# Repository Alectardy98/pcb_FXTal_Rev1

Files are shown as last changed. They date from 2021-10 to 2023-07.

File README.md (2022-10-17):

# FXTal Rev. 1 
    A Drop In Replacement PCB For The IBM Model F XT
                                            
capture-2022-10-17T17_19_43 746Z
capture-2022-10-17T17_19_39 296Z

All Supported Layouts can be seen [HERE](http://www.keyboard-layout-editor.com/#/gists/daab9567d1fe4691fd52719a6adab8b0)

xwhatsit/QMK atmega32u4 pcb for the IBM Model F XT and IBM Bigfoot

This version has been tested and has shown to function properly in both supported layouts.
- The firmware can be found in the firmware folder
- All files for production though JLCPCB can be found in the JLCPCB folder
- This pcb requires an xwhatsit to function, see [purdeaandrei's open source files](https://github.com/purdeaandrei/SMDModelFController)
- Test Points are currently on the pcb, when building make sure to cover the bottom test points with eletrical tape to prevent a short
- The origonal backplate will need to be modified to remove the right PCB mounting peg, to prevent interfearance
- The barrel Plate will need to be modified, a scan of the required holes are provided in folder meta, to help with the task

The PCB thickness should be 0.6mm or 0.08mm. This is thin enough to allow the board to flex into shape.
- 0.8mm tested and working

Standard glossy soldermask is probably the best choice. JLCPCB has had issues with wear on their black soldermask before. They have changed the formula, but a standard green/red/blue/yellow/purple/white/etc. glossy solder mask is probaby the safest bet for keyswitch wear resistance. Higher wear resistance might also be achieved by coating the front of the capacitive pads in silkscreen, as silkscreen is an extra layer of epoxy. I am unsure how this will affect keyfeel or actuation, however.

For connecting the board to an xwhatsit or other controller, I would recommend [3M 8132/06 100](https://www.digikey.com/en/products/detail/3m/8132-06-100/7809902), which has the correct pitch to connect this pcb to an xwhatsit

Capacitive pad footprints have been taken dvjs project the mtf-capacitive Other mesurements have been taken by NeonKight and myself from an origonal IBM F XT. The key matrix of the PCB is custom, made by myself guided by dvjs and purdeaandrei.

Released without warranty, use at your own risk.  
PRs & feedback welcome!

| Authors | 

Alectardy98

| Special Thanks |

djvs - for generial and overall help.   
NeonKnight - for mesurments and reversenginering.   
purdeaandrei - for writing the QMK firmware to work with xwhatsit.

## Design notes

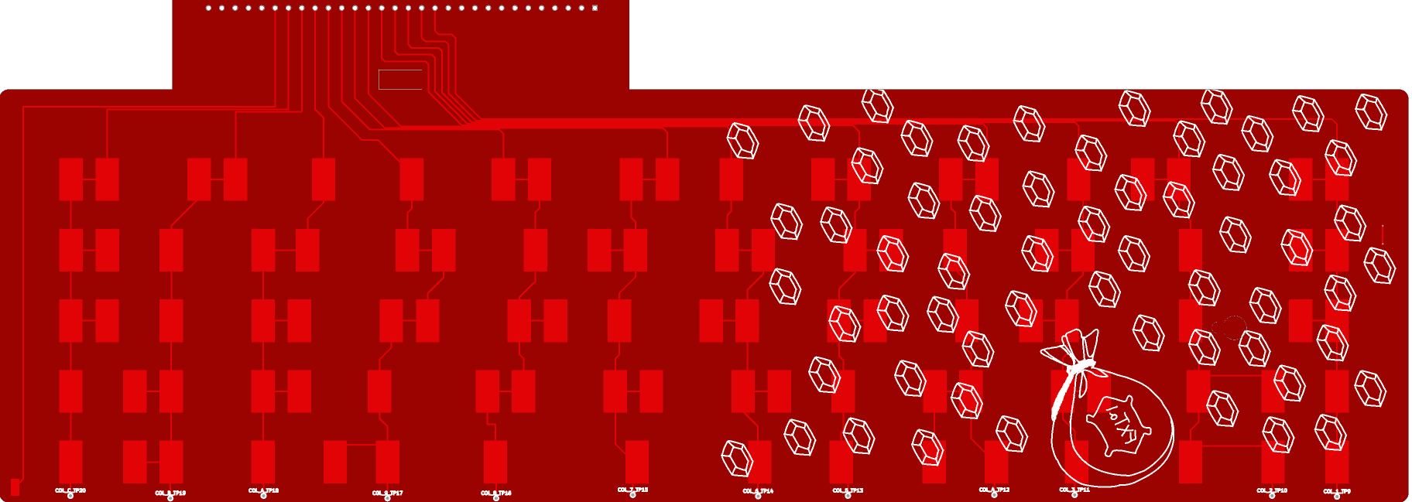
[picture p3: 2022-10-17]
meta/capture-2022-10-17T17_19_39.296Z.png

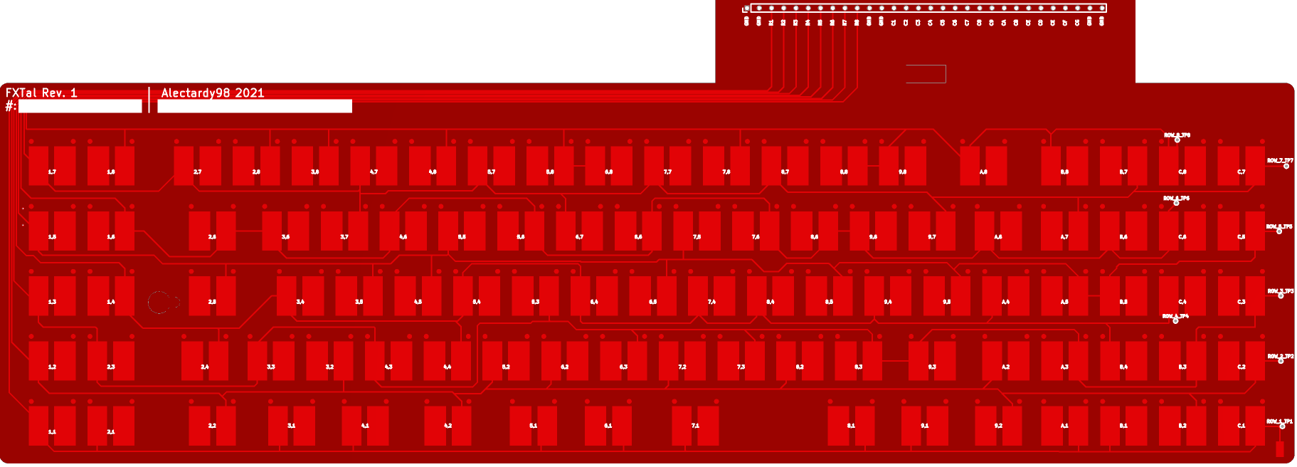
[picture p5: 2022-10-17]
meta/capture-2022-10-17T17_19_43.746Z.png

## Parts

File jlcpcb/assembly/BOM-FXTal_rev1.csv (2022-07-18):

Comment | Designator | Footprint | LCSC
1,7 | SW_25 | SW_CAP_IBM_F
1,8 | SW_26 | SW_CAP_IBM_F_ALT
2,7 | SW_22 | SW_CAP_IBM_F
2,8 | SW_1 | SW_CAP_IBM_F_ALT
3,8 | SW_02 | SW_CAP_IBM_F_ALT
4,7 | SW_03 | SW_CAP_IBM_F
4,8 | SW_04 | SW_CAP_IBM_F_ALT
5,7 | SW_05 | SW_CAP_IBM_F
5,8 | SW_06 | SW_CAP_IBM_F_ALT
6,8 | SW_07 | SW_CAP_IBM_F
7,7 | SW_08 | SW_CAP_IBM_F
7,8 | SW_09 | SW_CAP_IBM_F_ALT
8,7 | SW_0 | SW_CAP_IBM_F
8,8 | SW_47 | SW_CAP_IBM_F_ALT
9,8 | SW_21 | SW_CAP_IBM_F
A,8 | SW_13 | SW_CAP_IBM_F
B,8 | SW_63 | SW_CAP_IBM_F
B,7 | SW_66 | SW_CAP_IBM_F_ALT
C,8 | SW_67 | SW_CAP_IBM_F
C,7 | SW_68 | SW_CAP_IBM_F_ALT
1,5 | SW_27 | SW_CAP_IBM_F
1,6 | SW_28 | SW_CAP_IBM_F_ALT
2,6 | SW_90 | SW_CAP_IBM_F_ALT
3,6 | SW_74 | SW_CAP_IBM_F
3,7 | SW_93 | SW_CAP_IBM_F_ALT
4,6 | SW_19 | SW_CAP_IBM_F
5,5 | SW_76 | SW_CAP_IBM_F
5,6 | SW_89 | SW_CAP_IBM_F_ALT
6,7 | SW_95 | SW_CAP_IBM_F
6,6 | SW_91 | SW_CAP_IBM_F_ALT
7,5 | SW_37 | SW_CAP_IBM_F
7,6 | SW_51 | SW_CAP_IBM_F_ALT
8,6 | SW_65 | SW_CAP_IBM_F_ALT
9,6 | SW_42 | SW_CAP_IBM_F
9,7 | SW_78 | SW_CAP_IBM_F_ALT
A,6 | SW_12 | SW_CAP_IBM_F
A,7 | SW_69 | SW_CAP_IBM_F_ALT
B,6 | SW_70 | SW_CAP_IBM_F
C,6 | SW_71 | SW_CAP_IBM_F
C,5 | SW_72 | SW_CAP_IBM_F_ALT
1,3 | SW_29 | SW_CAP_IBM_F
1,4 | SW_30 | SW_CAP_IBM_F_ALT
2,5 | SW_15 | SW_CAP_IBM_F_ALT
3,4 | SW_10 | SW_CAP_IBM_F
3,5 | SW_83 | SW_CAP_IBM_F_ALT
4,5 | SW_17 | SW_CAP_IBM_F_ALT
5,4 | SW_24 | SW_CAP_IBM_F
5,3 | SW_35 | SW_CAP_IBM_F_ALT
6,4 | SW_36 | SW_CAP_IBM_F
6,5 | SW_38 | SW_CAP_IBM_F_ALT
7,4 | SW_39 | SW_CAP_IBM_F
8,4 | SW_40 | SW_CAP_IBM_F
8,5 | SW_84 | SW_CAP_IBM_F_ALT
9,4 | SW_75 | SW_CAP_IBM_F
9,5 | SW_50 | SW_CAP_IBM_F_ALT
A,4 | SW_20 | SW_CAP_IBM_F
A,5 | SW_73 | SW_CAP_IBM_F_ALT
B,5 | SW_53 | SW_CAP_IBM_F
C,4 | SW_54 | SW_CAP_IBM_F
C,3 | SW_55 | SW_CAP_IBM_F_ALT
1,2 | SW_31 | SW_CAP_IBM_F
2,3 | SW_32 | SW_CAP_IBM_F
2,4 | SW_45 | SW_CAP_IBM_F_ALT
3,3 | SW_49 | SW_CAP_IBM_F
3,2 | SW_96 | SW_CAP_IBM_F_ALT
4,3 | SW_94 | SW_CAP_IBM_F
4,4 | SW_14 | SW_CAP_IBM_F_ALT
5,2 | SW_92 | SW_CAP_IBM_F
6,2 | SW_11 | SW_CAP_IBM_F
6,3 | SW_48 | SW_CAP_IBM_F_ALT
7,2 | SW_46 | SW_CAP_IBM_F
7,3 | SW_16 | SW_CAP_IBM_F_ALT
8,2 | SW_18 | SW_CAP_IBM_F
8,3 | SW_85 | SW_CAP_IBM_F_ALT
9,3 | SW_81 | SW_CAP_IBM_F
A,2 | SW_82 | SW_CAP_IBM_F
A,3 | SW_56 | SW_CAP_IBM_F_ALT
B,4 | SW_57 | SW_CAP_IBM_F
B,3 | SW_58 | SW_CAP_IBM_F_ALT
C,2 | SW_59 | SW_CAP_IBM_F_ALT
1,1 | SW_33 | SW_CAP_IBM_F
2,1 | SW_23 | SW_CAP_IBM_F
2,2 | SW_43 | SW_CAP_IBM_F_ALT
4,1 | SW_41 | SW_CAP_IBM_F
8,1 | SW_77 | SW_CAP_IBM_F_ALT
A,1 | SW_60 | SW_CAP_IBM_F_ALT
B,1 | SW_61 | SW_CAP_IBM_F
B,2 | SW_62 | SW_CAP_IBM_F_ALT
C,1 | SW_64 | SW_CAP_IBM_F_ALT
CONN_CAP_IBM_F | J1 | CONN_CAP_IBM_F
4,2 | SW_34 | SW_CAP_IBM_F_ALT
3,1 | SW_44 | SW_CAP_IBM_F
9,1 | SW_80 | SW_CAP_IBM_F
9,1 | SW_52 | CAL_CAP_IBM_F
5,1 | SW_86 | SW_CAP_IBM_F_ALT
7,1 | SW_87 | SW_CAP_IBM_F
9,2 | SW_79 | SW_CAP_IBM_F_ALT
R1_TestPoint | ROW_1_TP1 | TestPoint_Pad_D1.0mm
R2_TestPoint | ROW_2_TP2 | TestPoint_Pad_D1.0mm
R3_TestPoint | ROW_3_TP3 | TestPoint_Pad_D1.0mm
R4_TestPoint | ROW_4_TP4 | TestPoint_Pad_D1.0mm
R5_TestPoint | ROW_5_TP5 | TestPoint_Pad_D1.0mm
R6_TestPoint | ROW_6_TP6 | TestPoint_Pad_D1.0mm
R7_TestPoint | ROW_7_TP7 | TestPoint_Pad_D1.0mm
R8_TestPoint | ROW_8_TP8 | TestPoint_Pad_D1.0mm
6,1 | SW_88 | SW_CAP_IBM_F_ALT
C7_TestPoint | COL_7_TP15 | TestPoint_Pad_D1.0mm
C9_TestPoint | COL_9_TP17 | TestPoint_Pad_D1.0mm
C8_TestPoint | COL_8_TP16 | TestPoint_Pad_D1.0mm
C4_TestPoint | COL_4_TP12 | TestPoint_Pad_D1.0mm
C1_TestPoint | COL_1_TP9 | TestPoint_Pad_D1.0mm
CB_TestPoint | COL_B_TP19 | TestPoint_Pad_D1.0mm
C6_TestPoint | COL_6_TP14 | TestPoint_Pad_D1.0mm
CA_TestPoint | COL_A_TP18 | TestPoint_Pad_D1.0mm
C3_TestPoint | COL_3_TP11 | TestPoint_Pad_D1.0mm
CC_TestPoint | COL_C_TP20 | TestPoint_Pad_D1.0mm
C2_TestPoint | COL_2_TP10 | TestPoint_Pad_D1.0mm
C5_TestPoint | COL_5_TP13 | TestPoint_Pad_D1.0mm

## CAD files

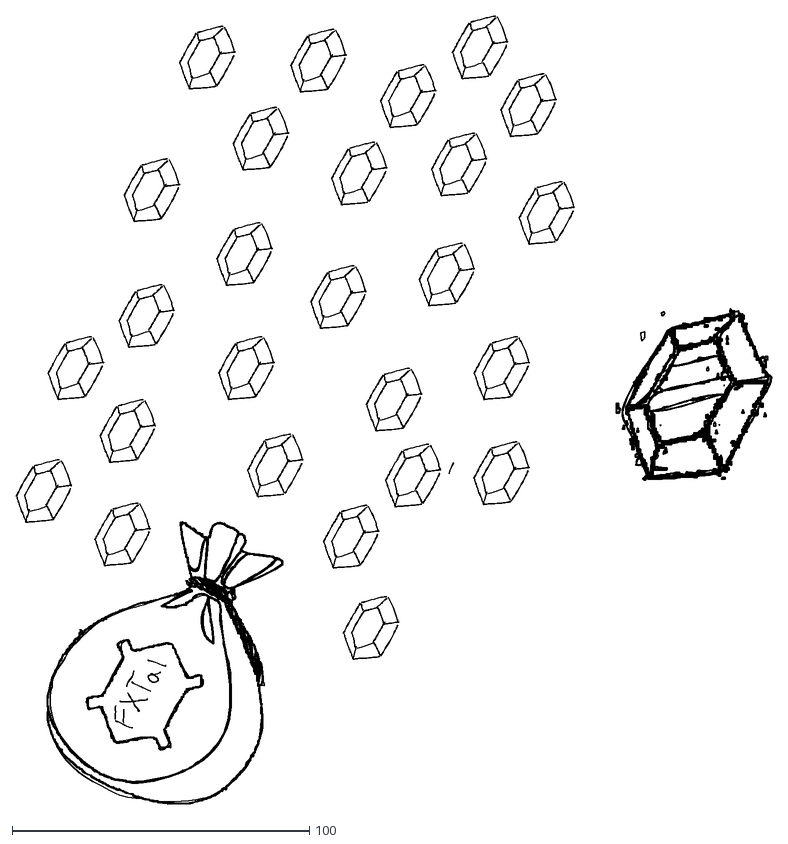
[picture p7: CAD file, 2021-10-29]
meta/art/FXTal.dxf
254.4 x 265.3

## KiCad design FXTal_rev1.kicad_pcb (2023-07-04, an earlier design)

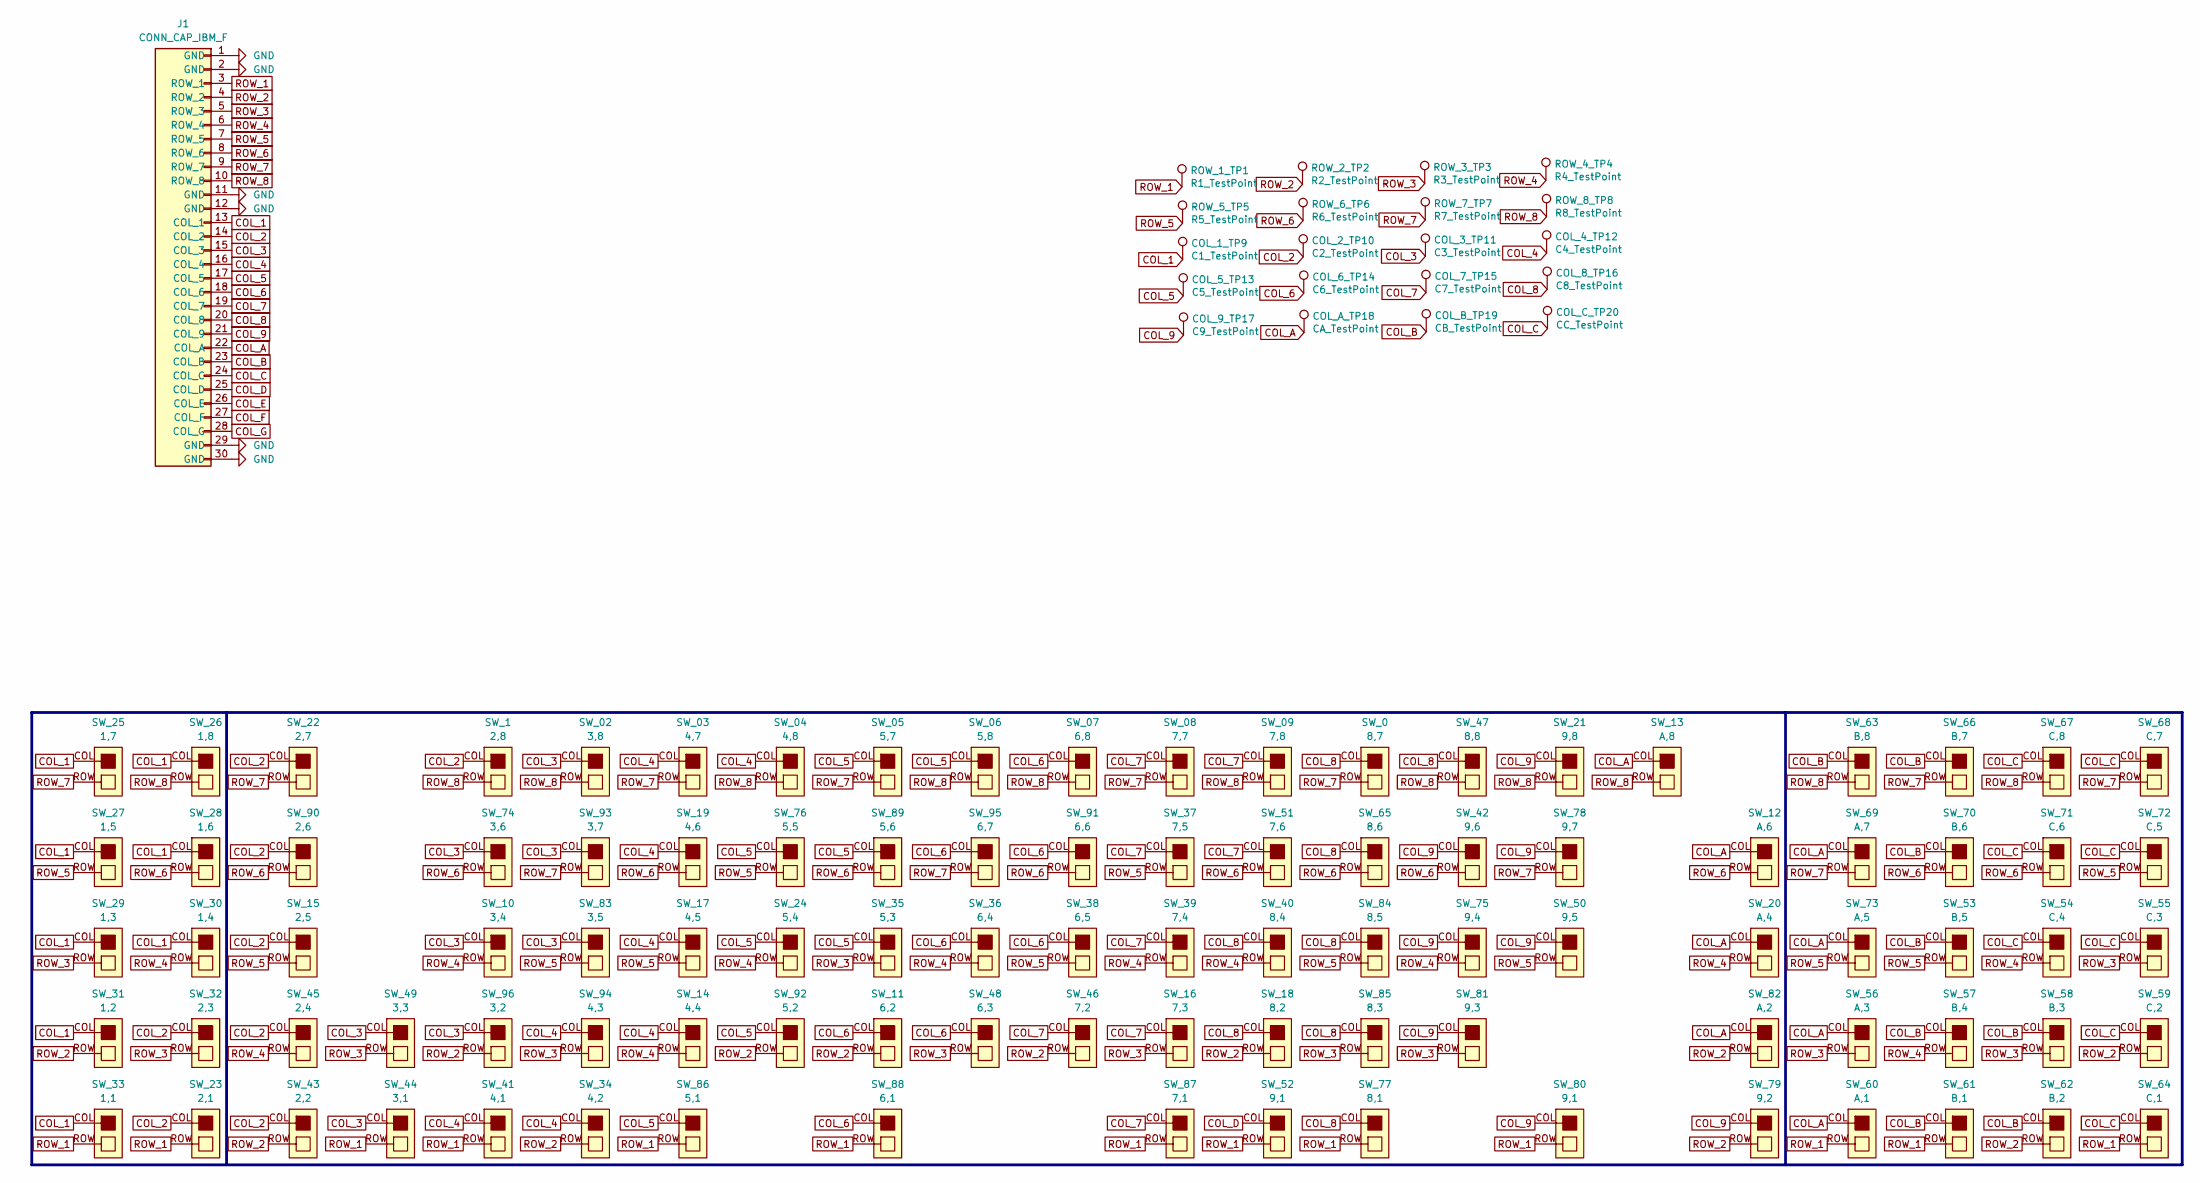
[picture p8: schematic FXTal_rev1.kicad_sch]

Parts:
COL_1_TP9: C1_TestPoint; TestPoint_Pad_D1.0mm
COL_2_TP10: C2_TestPoint; TestPoint_Pad_D1.0mm
COL_3_TP11: C3_TestPoint; TestPoint_Pad_D1.0mm
COL_4_TP12: C4_TestPoint; TestPoint_Pad_D1.0mm
COL_5_TP13: C5_TestPoint; TestPoint_Pad_D1.0mm
COL_6_TP14: C6_TestPoint; TestPoint_Pad_D1.0mm
COL_7_TP15: C7_TestPoint; TestPoint_Pad_D1.0mm
COL_8_TP16: C8_TestPoint; TestPoint_Pad_D1.0mm
COL_9_TP17: C9_TestPoint; TestPoint_Pad_D1.0mm
COL_A_TP18: CA_TestPoint; TestPoint_Pad_D1.0mm
COL_B_TP19: CB_TestPoint; TestPoint_Pad_D1.0mm
COL_C_TP20: CC_TestPoint; TestPoint_Pad_D1.0mm
J1: CONN_CAP_IBM_F
ROW_1_TP1: R1_TestPoint; TestPoint_Pad_D1.0mm
ROW_2_TP2: R2_TestPoint; TestPoint_Pad_D1.0mm
ROW_3_TP3: R3_TestPoint; TestPoint_Pad_D1.0mm
ROW_4_TP4: R4_TestPoint; TestPoint_Pad_D1.0mm
ROW_5_TP5: R5_TestPoint; TestPoint_Pad_D1.0mm
ROW_6_TP6: R6_TestPoint; TestPoint_Pad_D1.0mm
ROW_7_TP7: R7_TestPoint; TestPoint_Pad_D1.0mm
ROW_8_TP8: R8_TestPoint; TestPoint_Pad_D1.0mm
SW_0: 8,7; SW_CAP_IBM_F_ALT
SW_1: 2,8; SW_CAP_IBM_F
SW_02: 3,8; SW_CAP_IBM_F_ALT
SW_03: 4,7; SW_CAP_IBM_F
SW_04: 4,8; SW_CAP_IBM_F_ALT
SW_05: 5,7; SW_CAP_IBM_F
SW_06: 5,8; SW_CAP_IBM_F_ALT
SW_07: 6,8; SW_CAP_IBM_F
SW_08: 7,7; SW_CAP_IBM_F_ALT
SW_09: 7,8; SW_CAP_IBM_F
SW_10: 3,4; SW_CAP_IBM_F
SW_11: 6,2; SW_CAP_IBM_F
SW_12: A,6; SW_CAP_IBM_F_ALT
SW_13: A,8; SW_CAP_IBM_F
SW_14: 4,4; SW_CAP_IBM_F_ALT
SW_15: 2,5; SW_CAP_IBM_F
SW_16: 7,3; SW_CAP_IBM_F_ALT
SW_17: 4,5; SW_CAP_IBM_F
SW_18: 8,2; SW_CAP_IBM_F
SW_19: 4,6; SW_CAP_IBM_F
SW_20: A,4; SW_CAP_IBM_F
SW_21: 9,8; SW_CAP_IBM_F_ALT
SW_22: 2,7; SW_CAP_IBM_F_ALT
SW_23: 2,1; SW_CAP_IBM_F
SW_24: 5,4; SW_CAP_IBM_F_ALT
SW_25: 1,7; SW_CAP_IBM_F_ALT
SW_26: 1,8; SW_CAP_IBM_F
SW_27: 1,5; SW_CAP_IBM_F_ALT
SW_28: 1,6; SW_CAP_IBM_F
SW_29: 1,3; SW_CAP_IBM_F_ALT
SW_30: 1,4; SW_CAP_IBM_F
SW_31: 1,2; SW_CAP_IBM_F_ALT
SW_32: 2,3; SW_CAP_IBM_F
SW_33: 1,1; SW_CAP_IBM_F_ALT
SW_34: 4,2; SW_CAP_IBM_F
SW_35: 5,3; SW_CAP_IBM_F
SW_36: 6,4; SW_CAP_IBM_F_ALT
SW_37: 7,5; SW_CAP_IBM_F
SW_38: 6,5; SW_CAP_IBM_F
SW_39: 7,4; SW_CAP_IBM_F_ALT
SW_40: 8,4; SW_CAP_IBM_F
SW_41: 4,1; SW_CAP_IBM_F_ALT
SW_42: 9,6; SW_CAP_IBM_F
SW_43: 2,2; SW_CAP_IBM_F
SW_44: 3,1; SW_CAP_IBM_F_ALT
SW_45: 2,4; SW_CAP_IBM_F
SW_46: 7,2; SW_CAP_IBM_F_ALT
SW_47: 8,8; SW_CAP_IBM_F
SW_48: 6,3; SW_CAP_IBM_F_ALT
SW_49: 3,3; SW_CAP_IBM_F_ALT
SW_50: 9,5; SW_CAP_IBM_F_ALT
SW_51: 7,6; SW_CAP_IBM_F_ALT
SW_52: 9,1; CAL_CAP_IBM_F
SW_53: B,5; SW_CAP_IBM_F
SW_54: C,4; SW_CAP_IBM_F_ALT
SW_55: C,3; SW_CAP_IBM_F
SW_56: A,3; SW_CAP_IBM_F_ALT
SW_57: B,4; SW_CAP_IBM_F
SW_58: B,3; SW_CAP_IBM_F
SW_59: C,2; SW_CAP_IBM_F_ALT
SW_60: A,1; SW_CAP_IBM_F_ALT
SW_61: B,1; SW_CAP_IBM_F
SW_62: B,2; SW_CAP_IBM_F_ALT
SW_63: B,8; SW_CAP_IBM_F
SW_64: C,1; SW_CAP_IBM_F
SW_65: 8,6; SW_CAP_IBM_F
SW_66: B,7; SW_CAP_IBM_F_ALT
SW_67: C,8; SW_CAP_IBM_F
SW_68: C,7; SW_CAP_IBM_F_ALT
SW_69: A,7; SW_CAP_IBM_F_ALT
SW_70: B,6; SW_CAP_IBM_F
SW_71: C,6; SW_CAP_IBM_F
SW_72: C,5; SW_CAP_IBM_F_ALT
SW_73: A,5; SW_CAP_IBM_F_ALT
SW_74: 3,6; SW_CAP_IBM_F_ALT
SW_75: 9,4; SW_CAP_IBM_F
SW_76: 5,5; SW_CAP_IBM_F
SW_77: 8,1; SW_CAP_IBM_F_ALT
SW_78: 9,7; SW_CAP_IBM_F
SW_79: 9,2; SW_CAP_IBM_F_ALT
SW_80: 9,1; SW_CAP_IBM_F_ALT
SW_81: 9,3; SW_CAP_IBM_F
SW_82: A,2; SW_CAP_IBM_F
SW_83: 3,5; SW_CAP_IBM_F_ALT
SW_84: 8,5; SW_CAP_IBM_F_ALT
SW_85: 8,3; SW_CAP_IBM_F_ALT
SW_86: 5,1; SW_CAP_IBM_F
SW_87: 7,1; SW_CAP_IBM_F_ALT
SW_88: 6,1; SW_CAP_IBM_F_ALT
SW_89: 5,6; SW_CAP_IBM_F_ALT
SW_90: 2,6; SW_CAP_IBM_F_ALT
SW_91: 6,6; SW_CAP_IBM_F
SW_92: 5,2; SW_CAP_IBM_F_ALT
SW_93: 3,7; SW_CAP_IBM_F_ALT
SW_94: 4,3; SW_CAP_IBM_F
SW_95: 6,7; SW_CAP_IBM_F_ALT
SW_96: 3,2; SW_CAP_IBM_F

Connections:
COL_1: COL_1_TP9.1, J1.13 (COL_1), SW_25.COL, SW_26.COL, SW_27.COL, SW_28.COL, SW_29.COL, SW_30.COL, SW_31.COL, SW_33.COL
COL_2: COL_2_TP10.1, J1.14 (COL_2), SW_1.COL, SW_15.COL, SW_22.COL, SW_23.COL, SW_32.COL, SW_43.COL, SW_45.COL, SW_90.COL
COL_3: COL_3_TP11.1, J1.15 (COL_3), SW_02.COL, SW_10.COL, SW_44.COL, SW_49.COL, SW_74.COL, SW_83.COL, SW_93.COL, SW_96.COL
COL_4: COL_4_TP12.1, J1.16 (COL_4), SW_03.COL, SW_04.COL, SW_14.COL, SW_17.COL, SW_19.COL, SW_34.COL, SW_41.COL, SW_94.COL
COL_5: COL_5_TP13.1, J1.17 (COL_5), SW_05.COL, SW_06.COL, SW_24.COL, SW_35.COL, SW_76.COL, SW_86.COL, SW_89.COL, SW_92.COL
COL_6: COL_6_TP14.1, J1.18 (COL_6), SW_07.COL, SW_11.COL, SW_36.COL, SW_38.COL, SW_48.COL, SW_88.COL, SW_91.COL, SW_95.COL
COL_7: COL_7_TP15.1, J1.19 (COL_7), SW_08.COL, SW_09.COL, SW_16.COL, SW_37.COL, SW_39.COL, SW_46.COL, SW_51.COL, SW_87.COL
COL_8: COL_8_TP16.1, J1.20 (COL_8), SW_0.COL, SW_18.COL, SW_40.COL, SW_47.COL, SW_65.COL, SW_77.COL, SW_84.COL, SW_85.COL
COL_9: COL_9_TP17.1, J1.21 (COL_9), SW_21.COL, SW_42.COL, SW_50.COL, SW_75.COL, SW_78.COL, SW_79.COL, SW_80.COL, SW_81.COL
COL_A: COL_A_TP18.1, J1.22 (COL_A), SW_12.COL, SW_13.COL, SW_20.COL, SW_56.COL, SW_60.COL, SW_69.COL, SW_73.COL, SW_82.COL
COL_B: COL_B_TP19.1, J1.23 (COL_B), SW_53.COL, SW_57.COL, SW_58.COL, SW_61.COL, SW_62.COL, SW_63.COL, SW_66.COL, SW_70.COL
COL_C: COL_C_TP20.1, J1.24 (COL_C), SW_54.COL, SW_55.COL, SW_59.COL, SW_64.COL, SW_67.COL, SW_68.COL, SW_71.COL, SW_72.COL
COL_D: J1.25 (COL_D), SW_52.COL
COL_E: J1.26 (COL_E)
COL_F: J1.27 (COL_F)
COL_G: J1.28 (COL_G)
GND: J1.1 (GND), J1.2 (GND), J1.11 (GND), J1.12 (GND), J1.29 (GND), J1.30 (GND)
ROW_1: J1.3 (ROW_1), ROW_1_TP1.1, SW_23.ROW, SW_33.ROW, SW_41.ROW, SW_44.ROW, SW_52.ROW, SW_60.ROW, SW_61.ROW, SW_64.ROW, SW_77.ROW, SW_80.ROW, SW_86.ROW, SW_87.ROW, SW_88.ROW
ROW_2: J1.4 (ROW_2), ROW_2_TP2.1, SW_11.ROW, SW_18.ROW, SW_31.ROW, SW_34.ROW, SW_43.ROW, SW_46.ROW, SW_59.ROW, SW_62.ROW, SW_79.ROW, SW_82.ROW, SW_92.ROW, SW_96.ROW
ROW_3: J1.5 (ROW_3), ROW_3_TP3.1, SW_16.ROW, SW_29.ROW, SW_32.ROW, SW_35.ROW, SW_48.ROW, SW_49.ROW, SW_55.ROW, SW_56.ROW, SW_58.ROW, SW_81.ROW, SW_85.ROW, SW_94.ROW
ROW_4: J1.6 (ROW_4), ROW_4_TP4.1, SW_10.ROW, SW_14.ROW, SW_20.ROW, SW_24.ROW, SW_30.ROW, SW_36.ROW, SW_39.ROW, SW_40.ROW, SW_45.ROW, SW_54.ROW, SW_57.ROW, SW_75.ROW
ROW_5: J1.7 (ROW_5), ROW_5_TP5.1, SW_15.ROW, SW_17.ROW, SW_27.ROW, SW_37.ROW, SW_38.ROW, SW_50.ROW, SW_53.ROW, SW_72.ROW, SW_73.ROW, SW_76.ROW, SW_83.ROW, SW_84.ROW
ROW_6: J1.8 (ROW_6), ROW_6_TP6.1, SW_12.ROW, SW_19.ROW, SW_28.ROW, SW_42.ROW, SW_51.ROW, SW_65.ROW, SW_70.ROW, SW_71.ROW, SW_74.ROW, SW_89.ROW, SW_90.ROW, SW_91.ROW
ROW_7: J1.9 (ROW_7), ROW_7_TP7.1, SW_0.ROW, SW_03.ROW, SW_05.ROW, SW_08.ROW, SW_22.ROW, SW_25.ROW, SW_66.ROW, SW_68.ROW, SW_69.ROW, SW_78.ROW, SW_93.ROW, SW_95.ROW
ROW_8: J1.10 (ROW_8), ROW_8_TP8.1, SW_1.ROW, SW_02.ROW, SW_04.ROW, SW_06.ROW, SW_07.ROW, SW_09.ROW, SW_13.ROW, SW_21.ROW, SW_26.ROW, SW_47.ROW, SW_63.ROW, SW_67.ROW

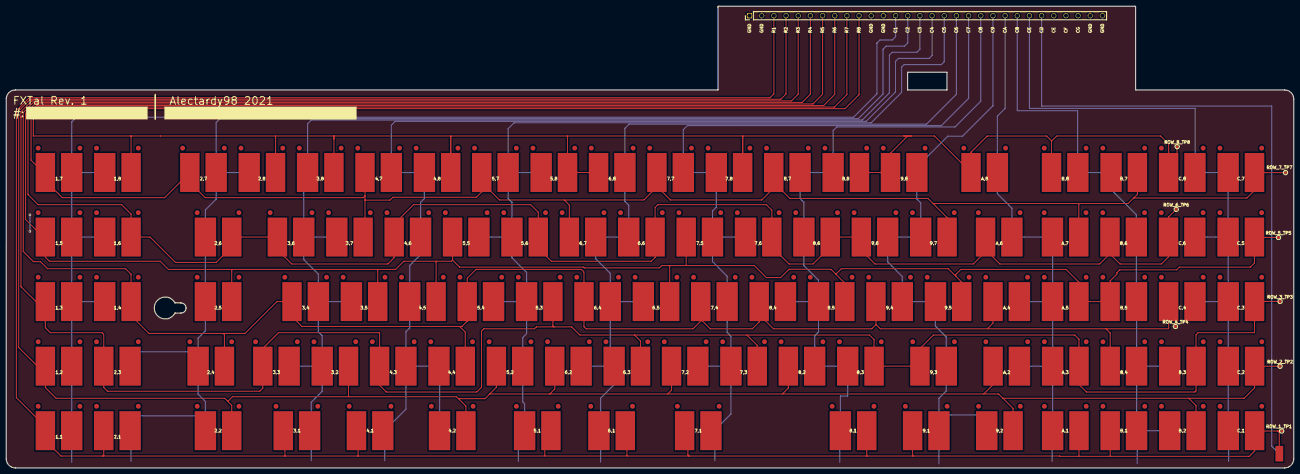
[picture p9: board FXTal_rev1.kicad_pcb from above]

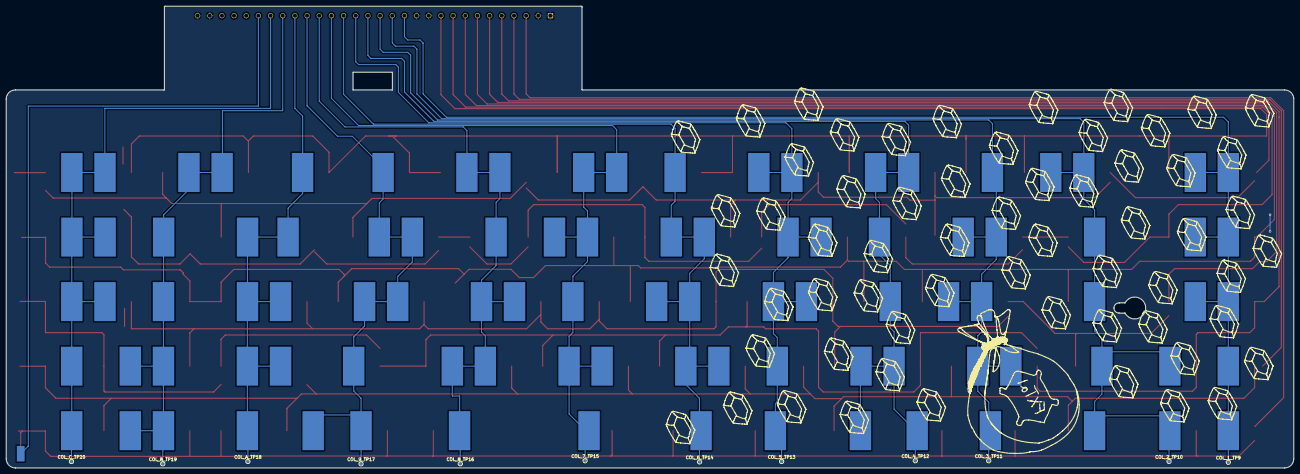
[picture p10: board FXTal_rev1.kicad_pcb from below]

Board: 2 copper layers, 419.0 x 150.2 mm, 118 parts (12 on the bottom side), 22 nets.

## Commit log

2021-12-13 firmware add
    [FXTal_no_holes.kicad_pcb]
2022-01-03 name change to rev 1
    [FXTal_no_holes-B_Cu.gbr, FXTal_no_holes-B_Fab.gbr, FXTal_no_holes-B_Mask.gbr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]
2022-01-03 changes to wireing
    [FXTal_rev1.kicad_pcb]
2022-01-03 push fix rev 1
    [FXTal_rev1.kicad_pcb, FXTal_rev1.kicad_sch, FXTal_rev1.sch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]
2022-07-18 Git Update Push
    [BOM-FXTal_rev1.csv, FXTal.dxf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]
2023-07-04 clean up
    [FXTal_rev1.kicad_pcb, FXTal_rev1.kicad_sch, FXTal_rev1.sch]
